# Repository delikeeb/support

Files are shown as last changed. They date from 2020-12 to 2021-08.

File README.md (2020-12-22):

# `dELIKEEb` Support Repository

This is a supporting repository for the keyboards that I made. All the keyboards here are hobby projects, and are not commercially available. 

README is under construction, but you check the folders if you need firmware for your keeb!

If you have question, PM me via `u/delikeeb`

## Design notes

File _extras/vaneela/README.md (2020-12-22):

# Flatbread60 Support Page

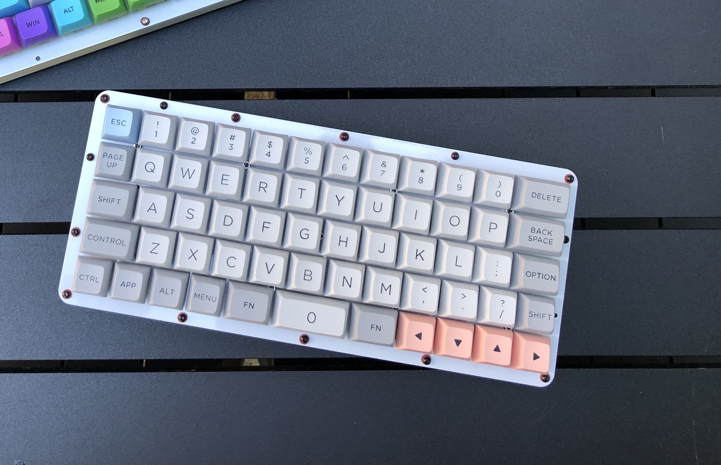
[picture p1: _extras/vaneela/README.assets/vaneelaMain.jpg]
vaneelaMain


## Pinout

MATRIX_ROW_PINS { F6, F7, B3, B2, B6 }

MATRIX_COL_PINS { F4, F5, B5, B4, E6, D7, C6, D4, D0, D1, D2, D3 }

## Firmware

I will push the firmware to the official QMK repo, so that you can use QMK configurator. Until then, you can compile the firmware using the raw file in the designated directory with a conventional QMK dev setup. Or, you can use the complied .hex file with QMK toolbox. The comilpled file has a `almost default` Preonic 48 key layout. Please check `keymap.c` file. 

## Housing Materials

- STL file for 3D printed middleware is uploaded, which is 16mm in height.

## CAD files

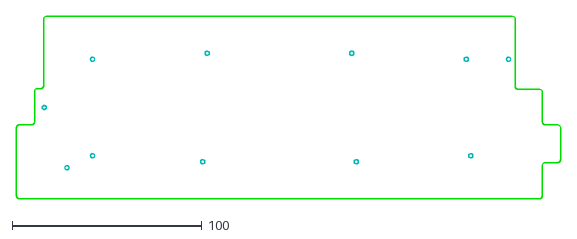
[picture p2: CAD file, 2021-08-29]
_extras/naan/prototypeCases/naan_rev1.5-plateCase_bottom.dxf
286.6 x 96.1

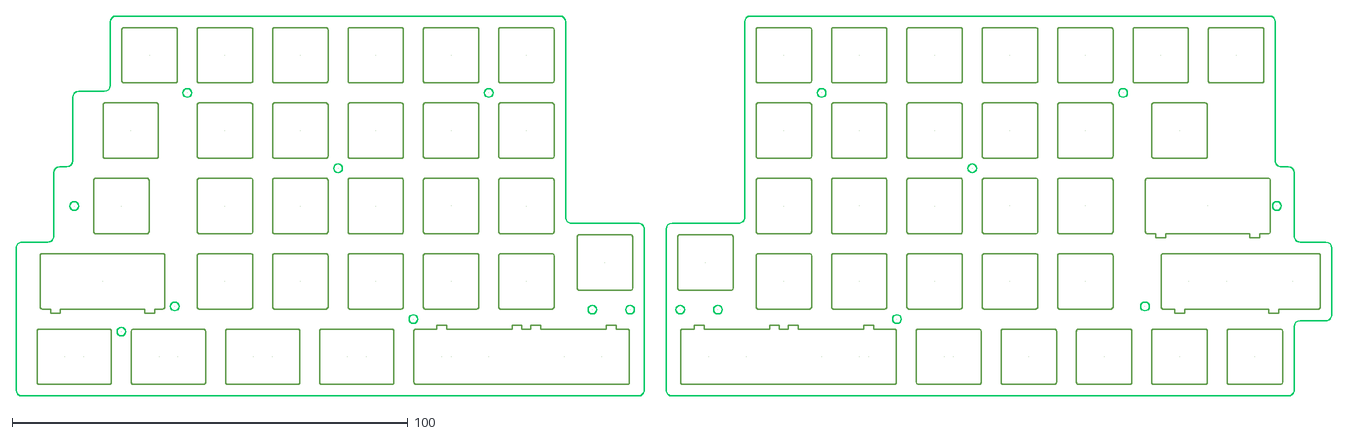
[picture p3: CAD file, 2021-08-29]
_extras/naanSplit/prototypeCases/naanSplit_rev2.x-platecase_switch.dxf
332.6 x 96.1

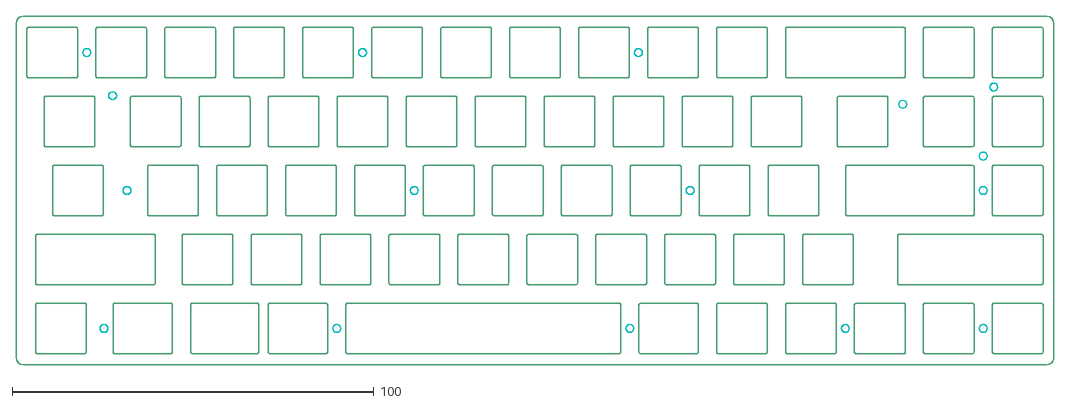
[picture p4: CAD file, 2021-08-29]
_extras/vaguetteLite/vaguetteLite_rev3.2-plateCase_switch.dxf
286.7 x 96.2

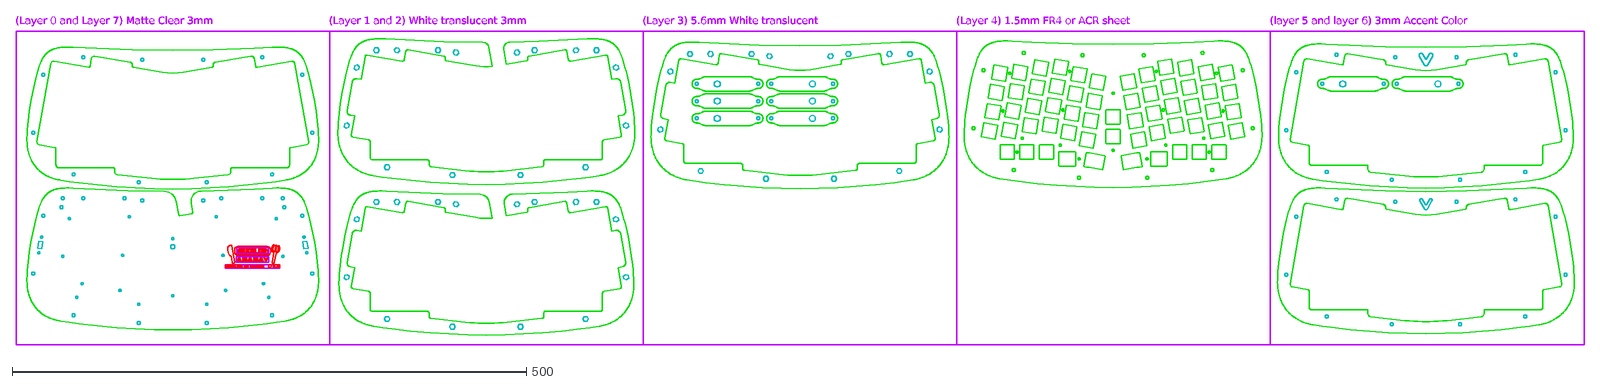
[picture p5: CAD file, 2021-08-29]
_extras/vanana/rev2.5_GB/ARC case/Vanana_rev2.5_GB_ACRcase_release.dxf
(layer 5 and layer 6) 3mm Accent Color
(Layer 3) 5.6mm White translucent
(Layer 1 and 2) White translucent 3mm
(Layer 4) 1.5mm FR4 or ACR sheet
(Layer 0 and Layer 7) Matte Clear 3mm

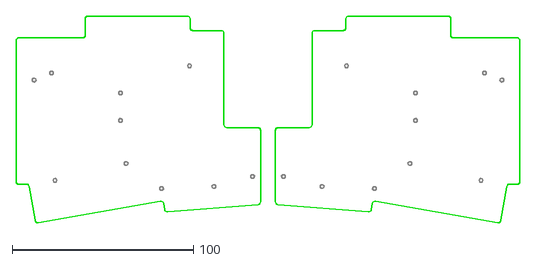
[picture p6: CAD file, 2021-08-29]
_extras/vananaSplit/prototypeCases/rev1.2/vananaSplit_rev1.2-plateCase_bottom.dxf
278.1 x 114.1

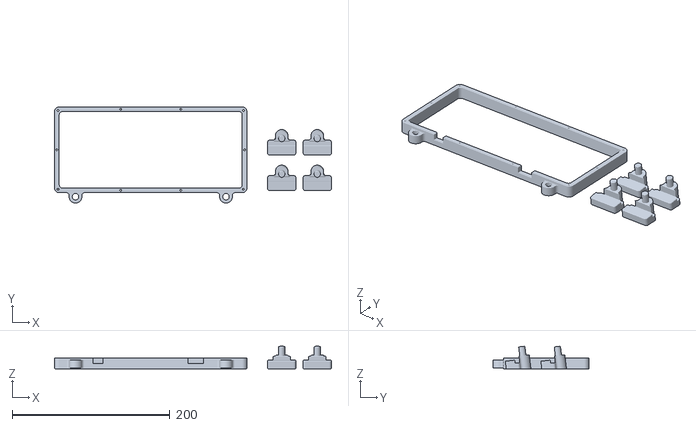
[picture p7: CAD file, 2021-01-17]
_extras/waaffle/plateCase_middleWare/middleware_60config.stl
350.7 x 121.8 x 28.7

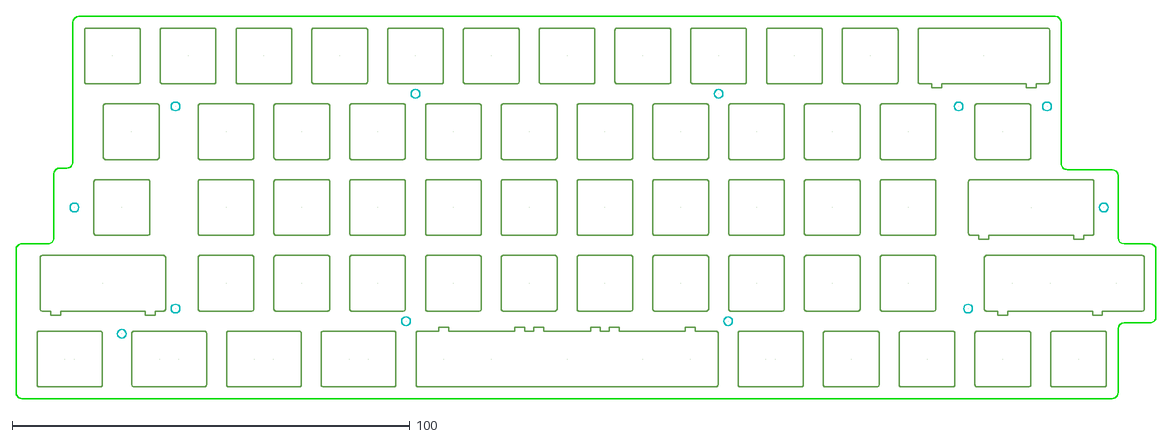
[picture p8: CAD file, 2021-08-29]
_extras/naan/prototypeCases/naan_rev1.5-plateCase_switch.dxf
286.6 x 96.1

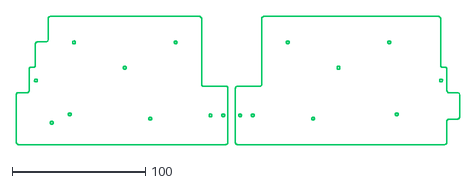
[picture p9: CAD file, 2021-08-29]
_extras/naanSplit/prototypeCases/naanSplit_rev2.x-platecase_bottom.dxf
332.6 x 96.1

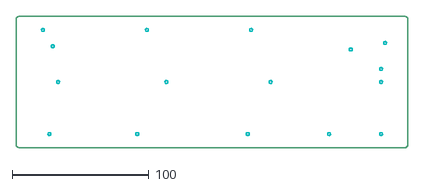
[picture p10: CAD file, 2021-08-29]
_extras/vaguetteLite/vaguetteLite_rev3.2-plateCase_bottom.dxf
286.7 x 96.2

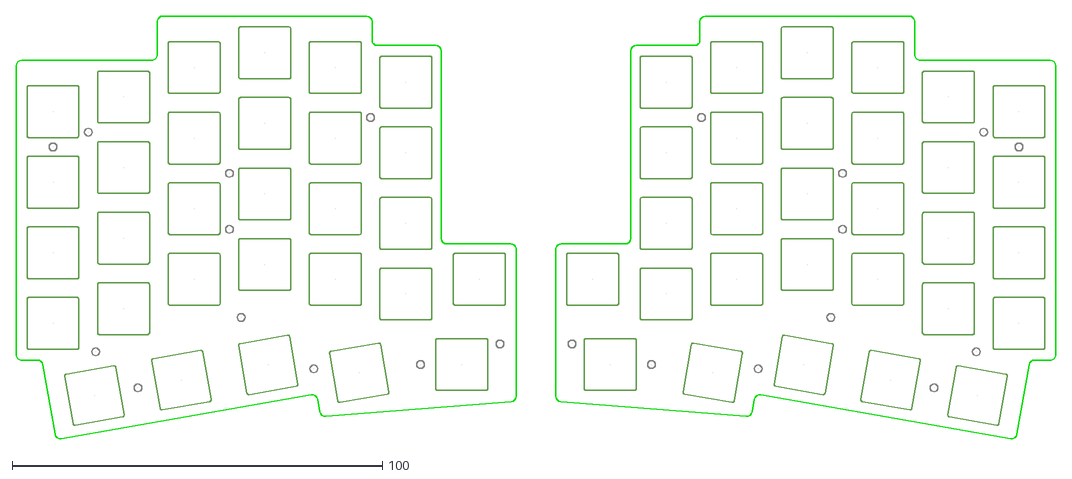
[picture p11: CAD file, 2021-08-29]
_extras/vananaSplit/prototypeCases/rev1.2/vananaSplit_rev1.2-plateCase_switch.dxf
280.6 x 114.1

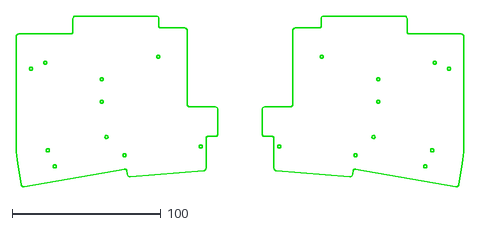
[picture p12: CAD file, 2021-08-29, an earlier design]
_extras/vananaSplit/prototypeCases/rev1.1/vananaSplit_rev1.1-plateCase_bottom.dxf
301.2 x 114.9

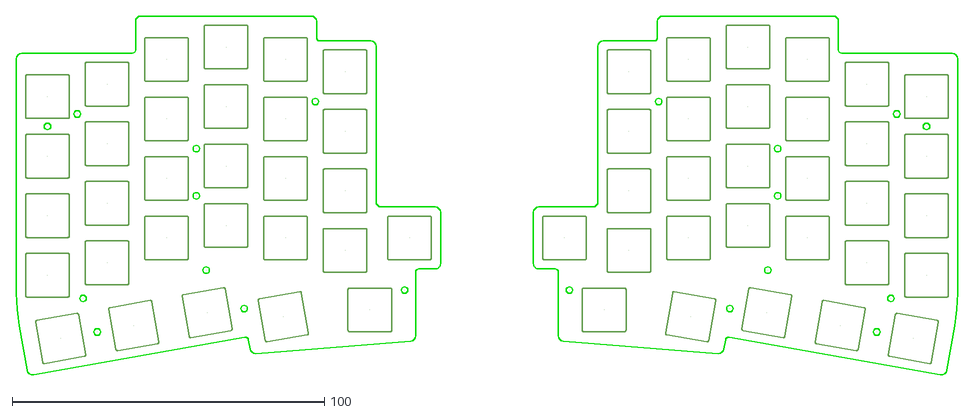
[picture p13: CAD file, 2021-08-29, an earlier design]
_extras/vananaSplit/prototypeCases/rev1.1/vananaSplit_rev1.1-plateCase_switch.dxf
301.2 x 114.9

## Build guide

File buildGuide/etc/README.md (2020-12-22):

# General guide for selecting/sourcing parts

This is a supporting repository for the keyboards that I made. All the keyboards here are a hobby project, and are not commercially available. 

## How to find and where to buy hardware?

When I sell some extra pieces, I usually do not include hardware because it's selection varies on your setup, e.g., soldered build, hot-swap build, ProMicro build and so on. Here I will write how to select parts to suit your build in my preferred way. However, do note that there is no right way to doing it. There are various ways to assemble a keyboard, so please take this as a reference. 

Most of the keyboards and cases that I make have the structure like this:

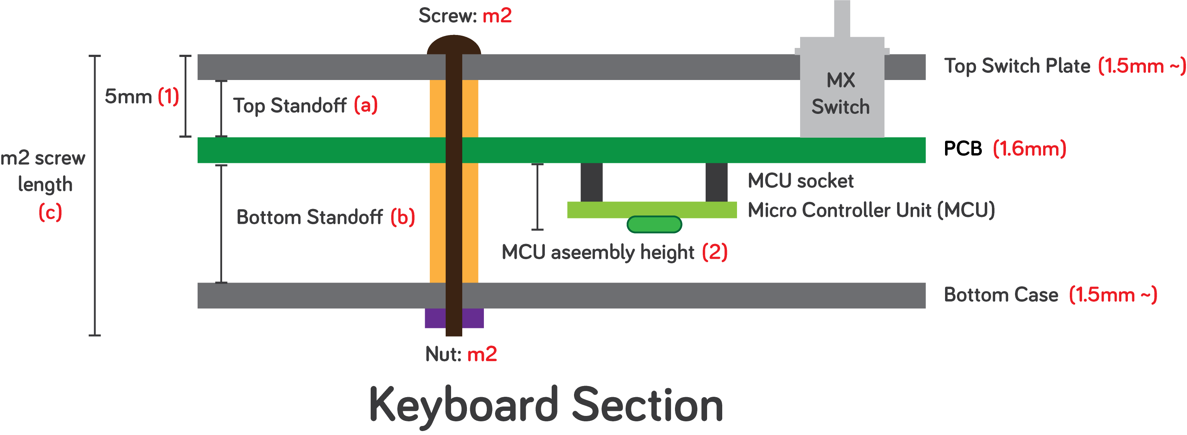
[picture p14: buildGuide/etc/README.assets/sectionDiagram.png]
sectionDiagram


As you can see here, you usually only need to decide the length of the standoffs (a), (b), and the length of a m2 screw (c). 

### Invariable factors

- Most single layered PCBs are 1.6mm in thickness. 
- Most stainless steel plates are 1.5mm in thickness.
- The distance between the top of PCB and the top of the switch plate **(1)** is 5mm when using MX switches. If you use 0305 Mil-Max hot-swap sockets, they will push the switches up about **0.5mm**, so the distance **(1)** will be about **5.5mm.**
- MCU assembly height **(2)** depends on your selection of parts. If want to go very cheap, you can use ProMicro and cheap machine pin sockets, and it will make the distance **(2)** **8mm**. If you want to go fancy, you can use ultra-low profile sockets and Elite-C, which will then make the distance **(2) 6mm.**

### Choosing a top standoff (a)

Based on the invariable  factor above,

-  If solder your switches and use a FR4 switch plate, you need a m2 standoff that fills 5mm - 1.6 mm = 3.4mm. Because a 3.4mm standoff does not exist, you can just use **3mm m2 standoff** and **0.5mm m2 washer**. 
- If you go for a hot-swap build with a 7304 Mil-Max socket, you you need a m2 standoff that fills 5.5mm - 1.6 mm = 3.9mm, and you can just use **4mm m2 standoff** . 

### Choosing a top standoff (b)

Based on the invariable  factor above,

- If you go with the cheap option, the minimum height of the bottom standoff (b) is **8mm.** 
- If you go with the fancy option, the minimum height of the bottom standoff (b) is **6mm.** 
- Choosing the minimum height may let your MCU touch the bottom case. 

### Choosing a screw (c)

Now you just need to add them up. To tighten things up with m2 nuts, you need about 2mm of a margin at the tip of s screw. So the length of the screw of your choice will be:

**Minimum screw length** = top switch plate thickness + top standoff height + PCB height (~1.6mm) + bottom standoff height + bottom case thickness + 2mm margin.

### Middleware height

If you want to add a middleware to prevent flexing in a FR4 case setup, the height of the middleware will be just the sum of the top and bottom standoff heights and the PCB thickness (1.6mm).

### Examples

- If you want to go with a cheapest setup with a FR4 plate case, Promicro, and soldered build: 
  - You can use 3mm standoffs and 0.5mm washers for the upper chamber.
  - You can use 8mm standoff for the lowerchamber.
  - You can use 3 + 1.6 + 8= 13.6 mm middleware. To make things simple, you can add 0.5mm washers to the bottom standoffs, and just make 14mm middleware.
  - The total thick of the case will be 1.6mm + 14mm (middleware) + 1.6mm = 17.2mm. So, You can use 20mm m2 screws.
- If you want to go with a fancy setup with a 0305 MilMax socket, SS plate, custom 3D printed case, Elite-C and ultra low profile sockets, and if we assume that the bottom plate of the 3D printed case is 3mm:
  - You can use 4mm standoffs for the upper chamber.
  - You can use 6mm standoffs for the upper chamber.
  - You can use   = 11.6 mm middleware. To make things simple, you can add 0.5mm washers to the bottom standoffs, and just make 12mm middleware.
  - The total thick of the case will be 1.5 mm (SS plate) + 12mm (middleware) + 3mm (3d printed case) = 16.5mm. So, you can use screws longer than 18.5 mm. 18mm will be also ok. 

## Where to buy?

Below are the places that I check for parts. 

https://docs.google.com/spreadsheets/d/1yFxFad6Fp7bDsbbrUbymgozWEZLEjbd6_0tXTSnRA-c/edit?usp=sharing

- For cheap items like screws and standoff:
  - Amazon: expensive, but takes a few days to be delivered. 
  - Walmart: somewhat expensive, and takes about two weeks to be delivered.
  - Aliexpress: dirt cheap, but takes forever to be delivered. 

If you are ok with a slow progression, I recommend to buy a bunch from Aliexpress. 

- For fancier items like ultra low profile sockets:
  - Digikey
  - Mouser

Do not buy cheap items like standoffs or screws from Digikey or Mouser. They are pretty expensive. I usually buy a lot of 18mm, 20mm screws and 4mm, 6mm, 8mm standoffs, and 0.5mm fiber washers.

### Note

- You can be flexible in sourcing parts. For example, If you need 8mm standoffs but could only find 7mm standoffs available, you can just buy 7mm ones and add two 0.5mm fiber washers. 

##  Where to make a custom case and plate?

- https://sendcutsend.com/
- https://www.treatstock.com/

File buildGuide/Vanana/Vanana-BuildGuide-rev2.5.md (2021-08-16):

# Vanana (rev 2.5 GB) Build Guide

Last Update: 210620

We will go through the process of fully assembling Vanana.

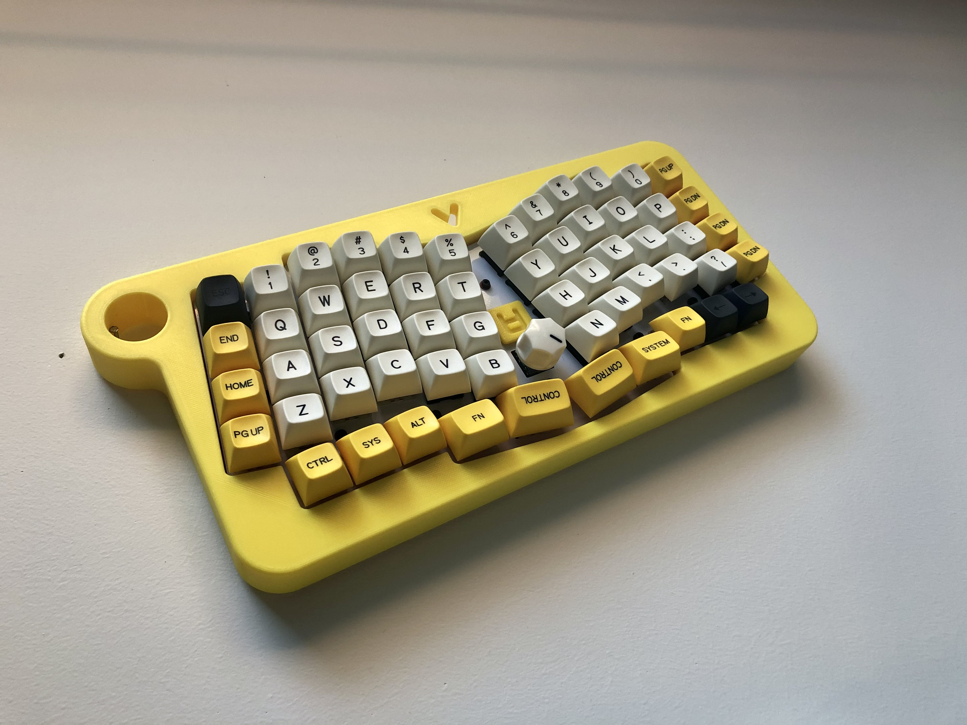
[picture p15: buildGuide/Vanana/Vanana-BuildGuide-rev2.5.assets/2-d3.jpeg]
2-d3


## Required Hardware:

**Overview** 

01-Overview@2x

**Hardware used to make this build:** 

- Vanana Thicc Case x 1 
- Vanana Plate x 1 
- m2 screws 7mm x 4
- m2 screws 18mm x 12
- m2 Standoff 5mm x 12 
- m2 Standoff 4mm x 12
- m2 Nuts x 12
- m2 Washer x 12 
- EC11 Rotary Encoder x 1 (optional)
- Dupont cable x 3 (optional for the encoder 2 or RGB) 
- Right angle headers x 9 (optional)
- Straight angle headers (This usually comes with your MCU. Make sure that the height of the insulation is less than or equal to 3mm)

**Optional hardware for a wireless build:** 

- Dupont cable x 6 (2 cables for RGB, Power switches, and battery) 
- Slide Switch x 2
- LiPo Battery **(will not be included in the GB kit)**

**Optional hardware for a Hot-swap functionality:** 

- Ultra-low profile Pin Socket (for a MCU board) 
- Round machine pin x 12 (for a MCU board) 
- Mil Max 0305 x 120 (for key switches) 

**And, of course:**

- MCU board of your choice (Pro Micro, Elite-C, Nice!nano)
- Switches and keycaps.

**Useful quality-of-life tools (links are only for reference):**

- Masking tape like [this one](https://www.amazon.com/AmazonBasics-Masking-Tape-Inch-Rolls/dp/B07QHSKGMH)
- M2 hex nut driver like [this one](https://www.amazon.com/uxcell-Non-Magnetic-Point-Driver-3-Inch/dp/B07DXZJQ4S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)
- M2 hex driver like [this one](https://www.amazon.com/gp/product/B001ATKWJY/ref=ppx_yo_dt_b_search_asin_title?ie=UTF8&psc=1) 
- or, the all-in-one driver set [this one](https://www.amazon.com/iFixit-IF145-299-4-Driver-Bit-64pc/dp/B0189YWOIO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)

## Assembly Order

1. Soldering on PCB: MCU Board sockets and right-angle headers
2. Switchplate Assembly
3. (if your build is soldered) Keyboard Switches
4. (if your build is hot-swappable) Hot-swap sockets
5. Assembling MCU board onto the PCB
6. (if your build is wireless) Battery and external Switches

## Assembly instruction

### Step 1. Soldering on PCB: MCU Board sockets and right-angle headers

On the Group buy version, all the essential parts are pre-soldered, which includes:

- Diodes
- Capacitors
- 2x onboard slide switches
- Reset switch
- RGB Underglow LEDs

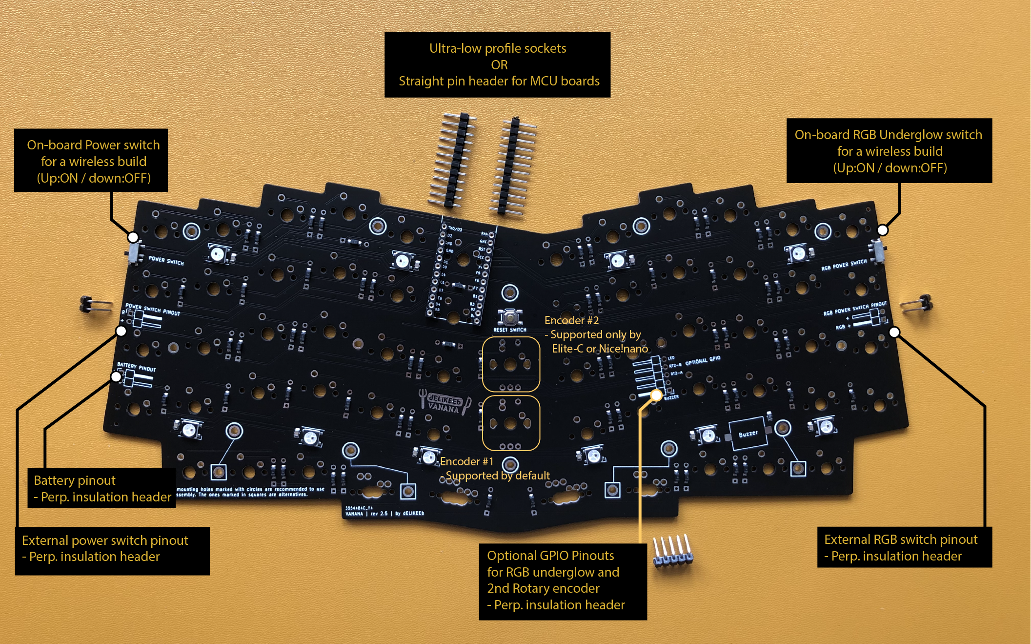
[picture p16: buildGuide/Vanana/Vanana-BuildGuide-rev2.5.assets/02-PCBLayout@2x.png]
02-PCB Layout@2x
You only need to solder a few parts on PCB and assemble an MCU board on it. 

**Parts you need:**

- Ultra-low MCU board sockets **or** straight pin headers. 
- (wireless setup only) 3 x 2-pos Right angle headers.
- (Optional for RGB underglow and the encoder 2) 1 x 3-pos (or 5) Right angle header.
- **Note*: with GB version PCBs, you can use a right-angle header with a parallel insulation for external switches and battery connections. Extra GPIOs will still need the one with a perpendicular insulation.**  

**Steps**:

1. Insert ultra-low profile sockets (for a hot-swap build) **or** straight pin headers (for a soldered build) from the back of the PCB. The photo below shows compatible sockets and headers. You will use **one of them** depending on your build. Make sure the height of the insulations of the header or sockets (black plastic part in the photo below) are less than or equal to 3mm. Most straight pin headers that come with MCU boards have insulations whose height is less than 3mm. Masking tape will help you secure the parts when soldering them. Solder MCU sockets or headers from the front of the PCB.
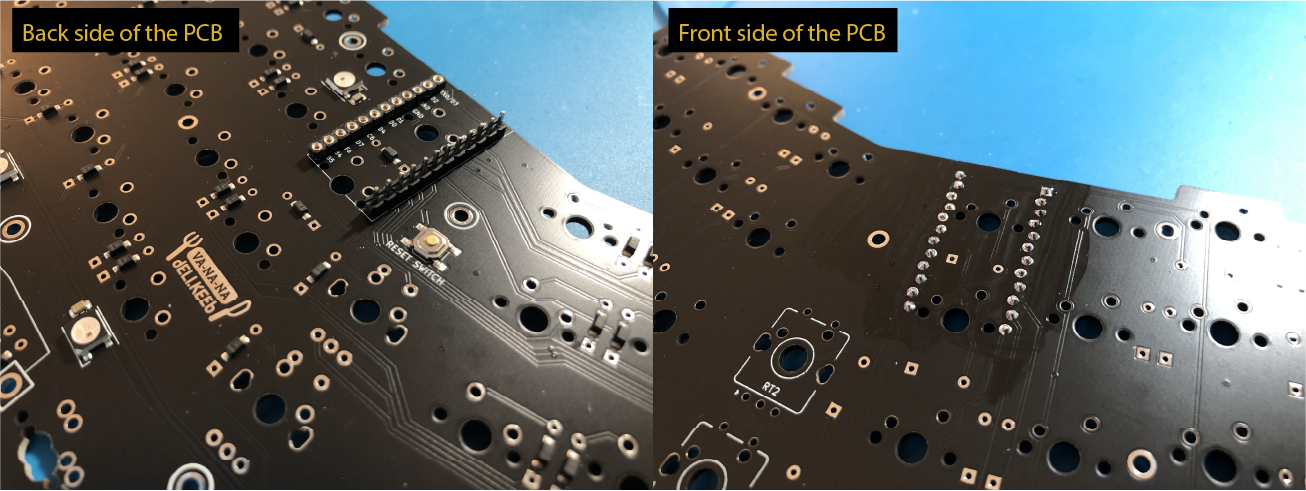
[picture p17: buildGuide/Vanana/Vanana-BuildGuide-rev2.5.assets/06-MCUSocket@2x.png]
06-MCU socket@2x
   
2. Note that there are two onboard switches on both sides of the PCB. One is for RGB, and the other is for the Power switch. (Down: OFF/ Up: ON). If you are building a **wired Vanana, just toggle up the switches and skip to the next section (Step 2. Switch Plate Assembly). If you are building a wireless Vanana with a plate case kit**, you can also skip to the next section.
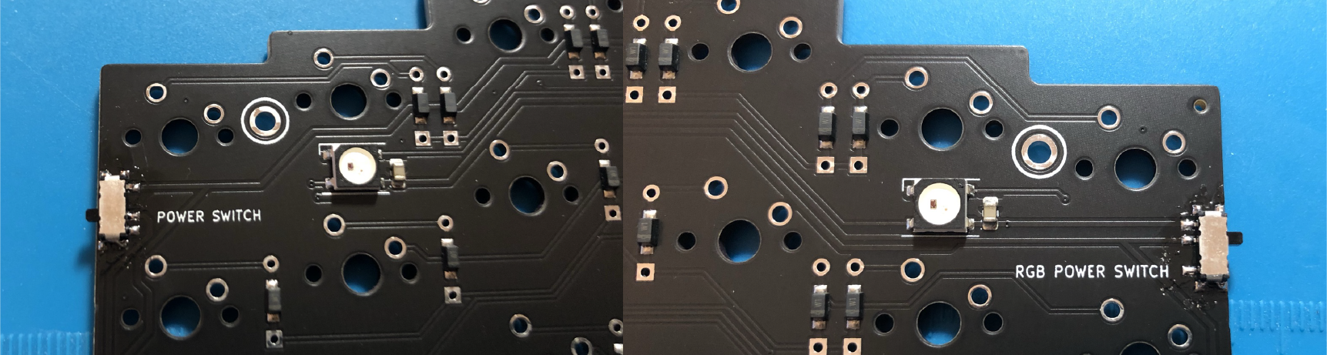
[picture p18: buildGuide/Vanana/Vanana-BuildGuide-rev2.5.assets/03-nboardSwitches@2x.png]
03-nboardSwitches@2x
   
3. If you are building a **wireless Vanana with 3D printed cases**, it is time to solder 3 x 2-pos right-angle pin headers to use external switches and batteries. 
   - At the time of designing the board, the RGB switch was added to cut off the quiescent current draw of RGB LEDs. Now the software RGB control of ZMK is equivalent to the hardware switch, so you can skip soldering the RGB switch header pin if you do not mind using a software switch to control RGB underglow.
   - Note that there are two types of right-angle headers included. Use the one with an insulation perpendicular to the PCB for this step. The other one will be used to mod an MCU board.
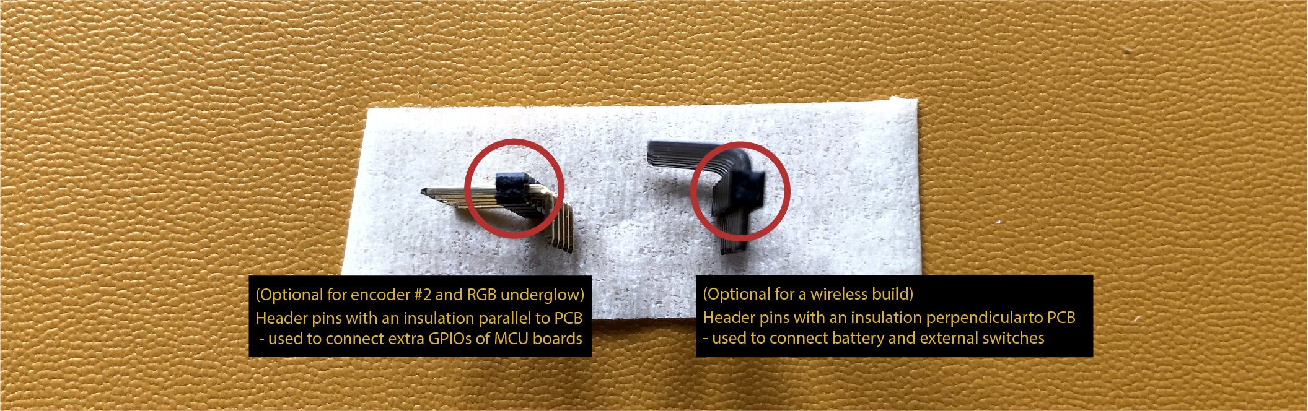
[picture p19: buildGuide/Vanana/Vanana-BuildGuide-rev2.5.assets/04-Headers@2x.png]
04-Headers@2x
     

- Prepare the headers as shown in the photo. Place the right-angle pin headers on the back of the PCB. You may want to use tape to secure the header. Solder the pin headers from the front of the PCB. Place the header pins flat on the PCB. 
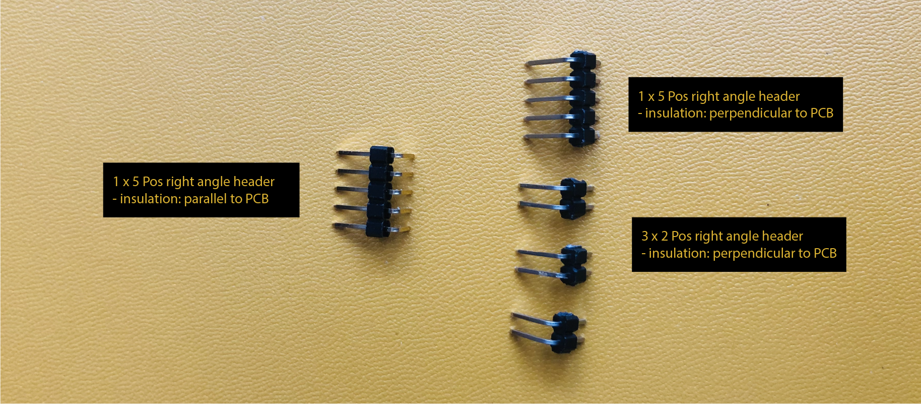
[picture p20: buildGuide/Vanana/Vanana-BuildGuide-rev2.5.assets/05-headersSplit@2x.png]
05-headers split@2x
  
- Solder the right angle headers onto the PCB as shown in the photo. Masking tape will help you secure the parts. There are three places to install the 2-pos headers. Place the headers on the back of the PCB, and solder them from the front. 
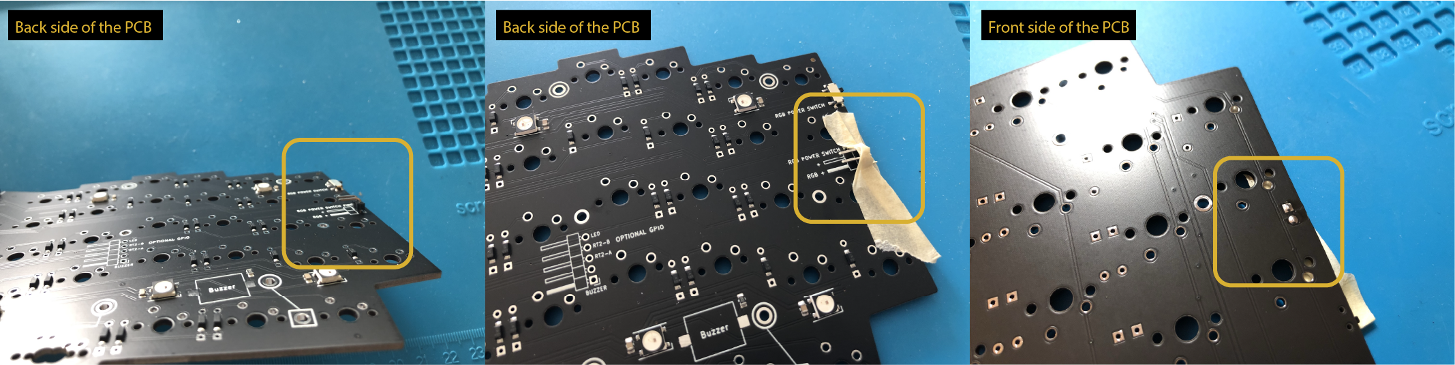
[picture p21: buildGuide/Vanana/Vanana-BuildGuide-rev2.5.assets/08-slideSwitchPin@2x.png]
08-slideSwitchPin@2x
  

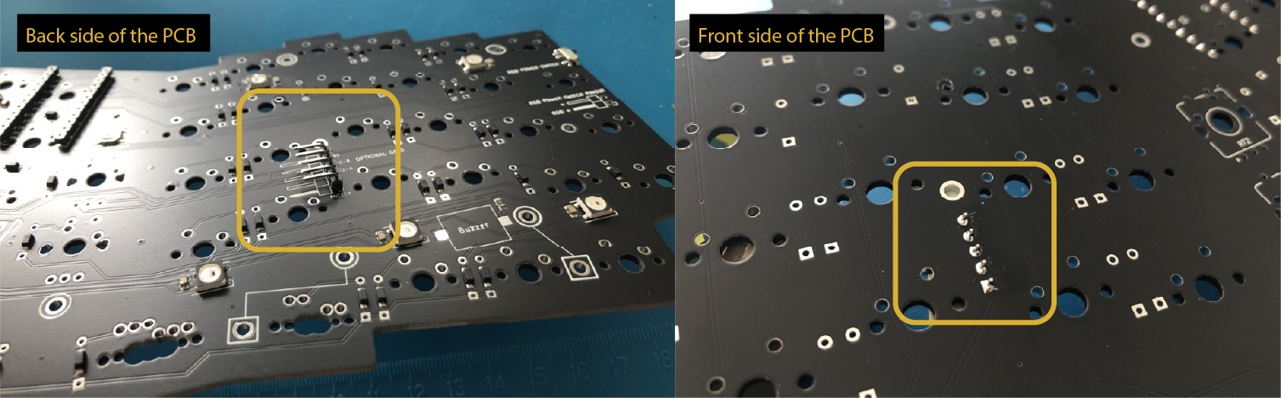
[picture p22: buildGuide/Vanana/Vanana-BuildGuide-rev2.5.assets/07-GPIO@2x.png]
07-GPIO@2x
4. If you want to enable RGB underglow or the encoder at position 2, solder the header on the PCB as below. The procedure is the same as the step above. 
5. If you are going to use rotary encoders, solder it on the PCB.
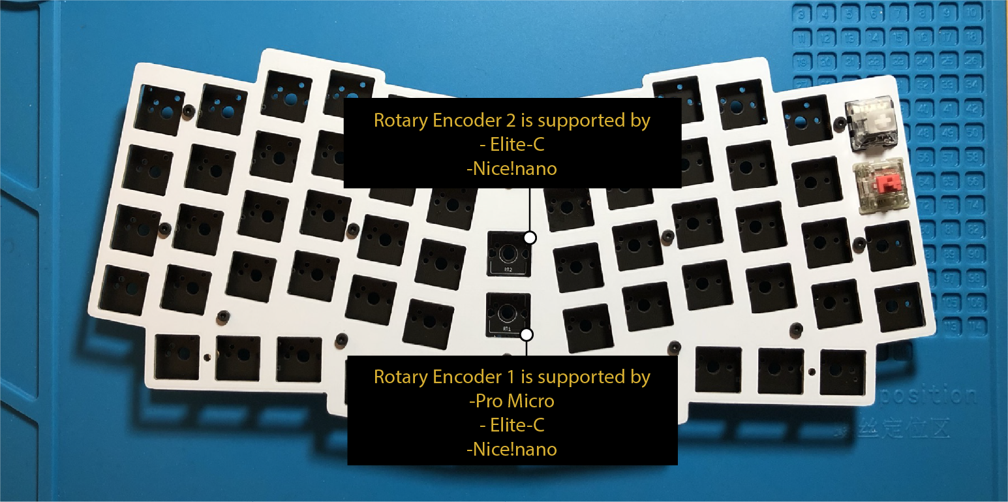
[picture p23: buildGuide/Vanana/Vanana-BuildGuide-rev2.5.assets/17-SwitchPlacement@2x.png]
17-Switch placement@2x
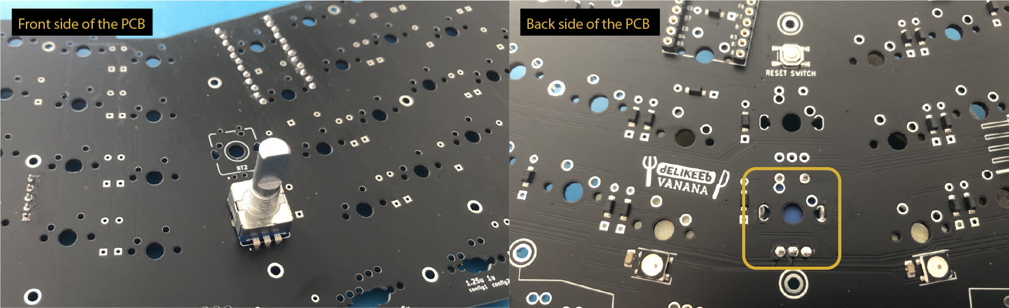
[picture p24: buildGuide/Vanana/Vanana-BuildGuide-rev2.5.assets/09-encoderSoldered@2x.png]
09-encoder soldered@2x
   - A rotary encoder at position 1 is supported by all Pro Micro compatibles and Nice!nano by default. However, only Nice!nano and Elite-C supports a rotary encoder at position 2 because it uses extra GPIO pins on Elite-C and Nano, which will be covered in the later section. Likewise, RGB underglow is supported only with Elite-C and Nice!Nano.

### Step 2. Switch Plate Assembly

**Parts you need:**

- 12 x m2 screws 
- 12 x Short m2 standoffs

**Steps**:

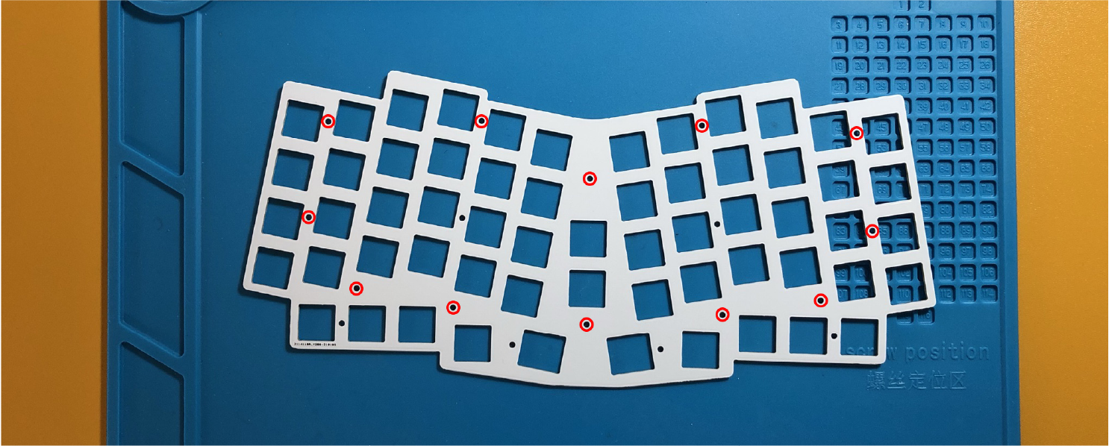
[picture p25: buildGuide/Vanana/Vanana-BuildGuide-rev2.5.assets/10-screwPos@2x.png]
10-screwPos@2x
1. You are free to change the positions of screws at your preference. The ones marked red in the photo above are the recommended locations.
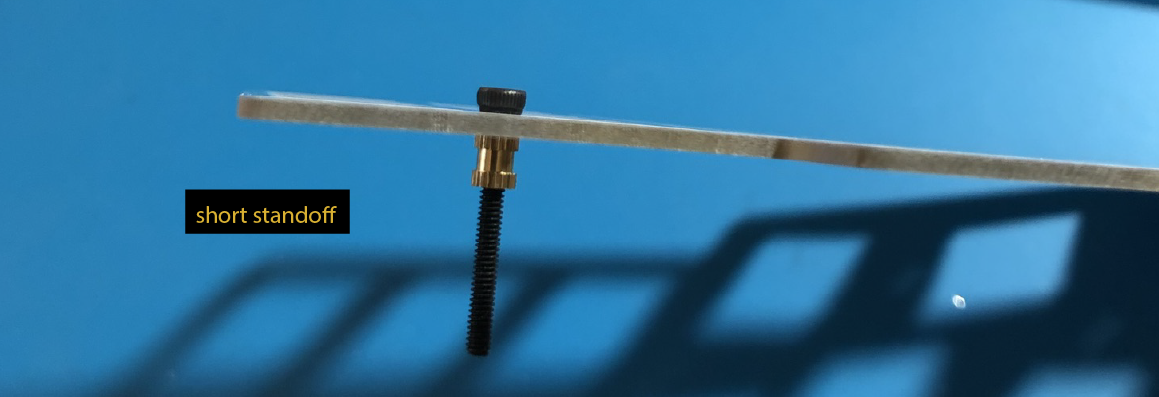
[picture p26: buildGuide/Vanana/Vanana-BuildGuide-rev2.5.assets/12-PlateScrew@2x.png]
12-PlateScrew@2x
2. Insert screws into the switch plate from the top.
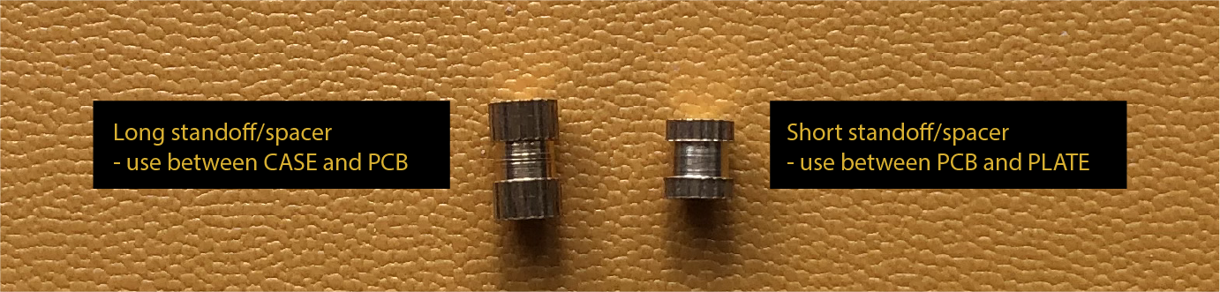
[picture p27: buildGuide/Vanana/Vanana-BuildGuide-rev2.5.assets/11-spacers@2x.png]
11-Artboard 25@2x
3. Insert **short M2 standoffs/spacers** (4mm one in GB version kits) and tighten them. You can do this by hand. However, if you want a rock-solid build, use a small plier to hold the standoffs/spacers and an m2 hex screwdriver to tighten them). 
4. Assemble the PCB and the switch plate. Place **the long standoffs** and tighten them.  
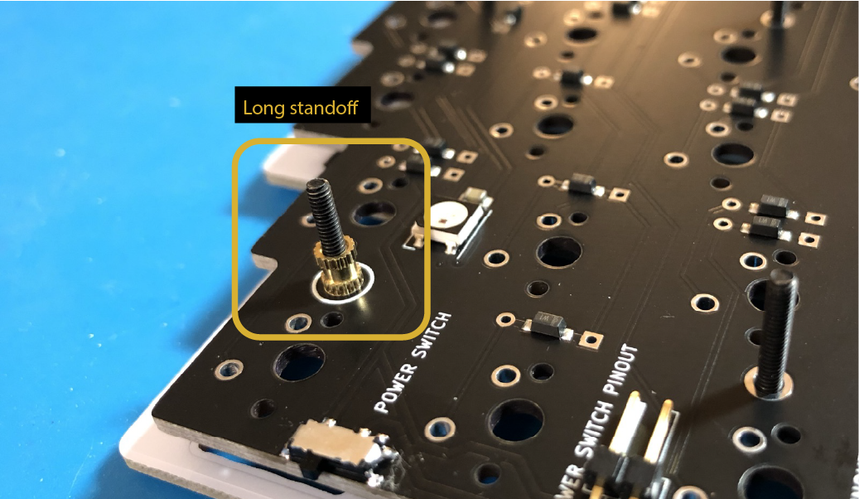
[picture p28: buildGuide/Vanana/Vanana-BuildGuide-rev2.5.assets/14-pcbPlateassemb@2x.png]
14-pcbPlateassemb@2x
   
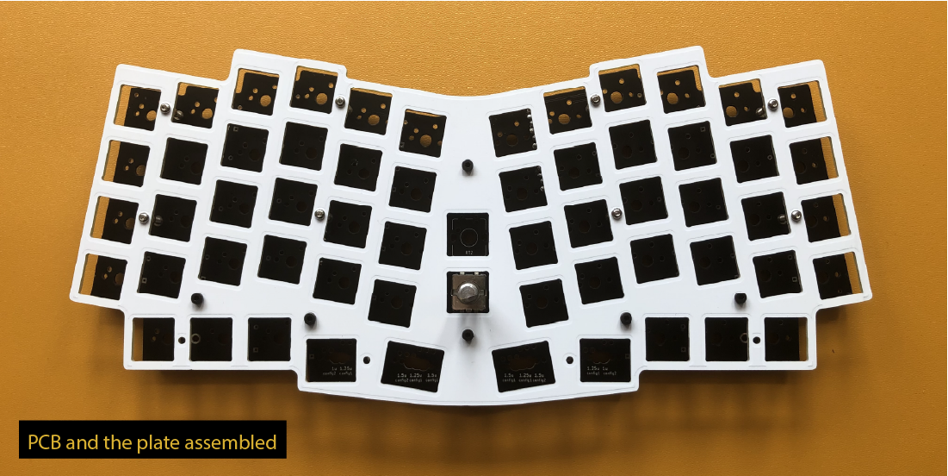
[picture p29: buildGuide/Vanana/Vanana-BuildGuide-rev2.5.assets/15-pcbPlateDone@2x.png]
15-pcb plate done@2x
   

### Step 3. (if your build is soldered) Keyboard Switches

**Parts you need:**

- 60 x keyboard switches

**Steps:**

1. Vanana GB version supports three layouts. Choose your layout and insert switches into the appropriate positions.
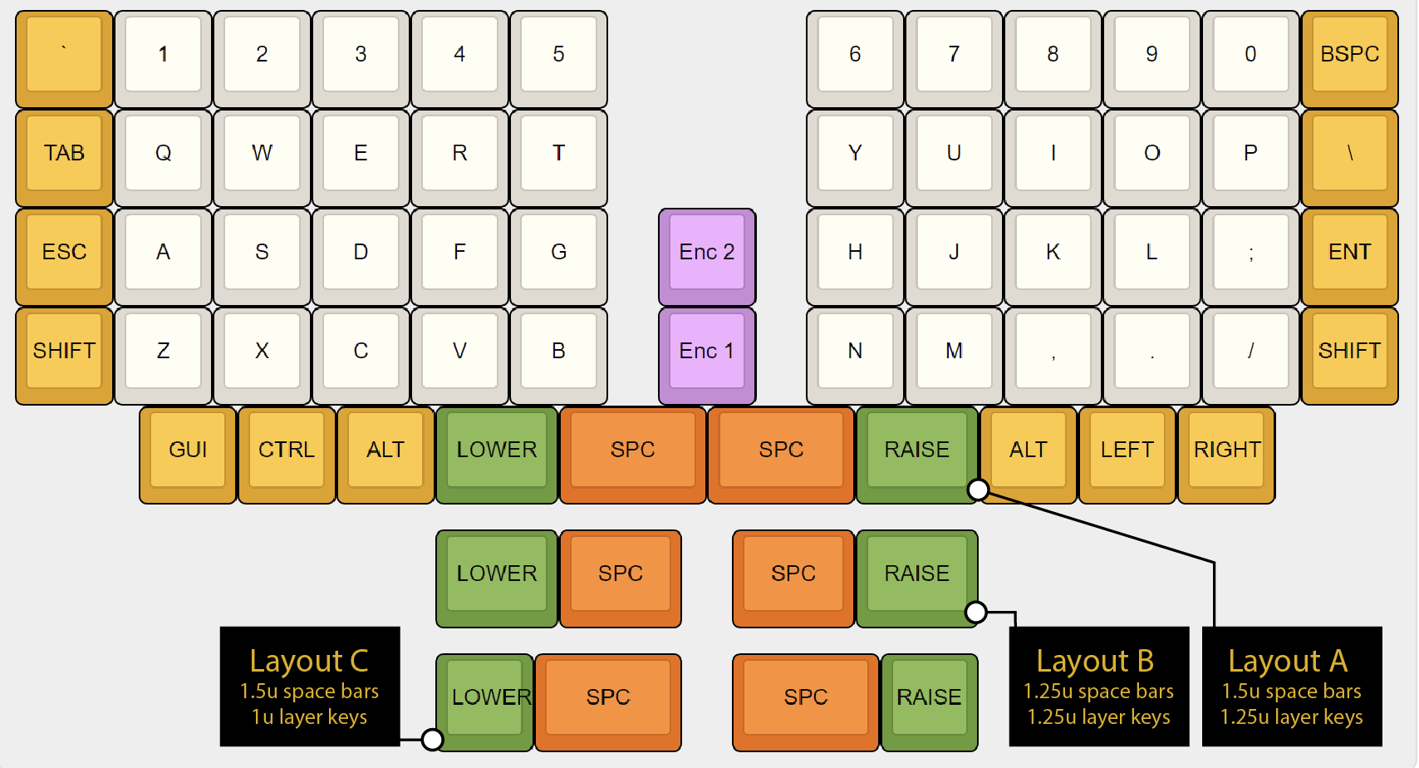
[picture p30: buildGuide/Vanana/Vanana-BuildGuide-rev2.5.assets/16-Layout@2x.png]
16-Layout@2x
   
2. Plate switches on the plate. Make sure that all the switches are fully inserted into the holes on the plate. 
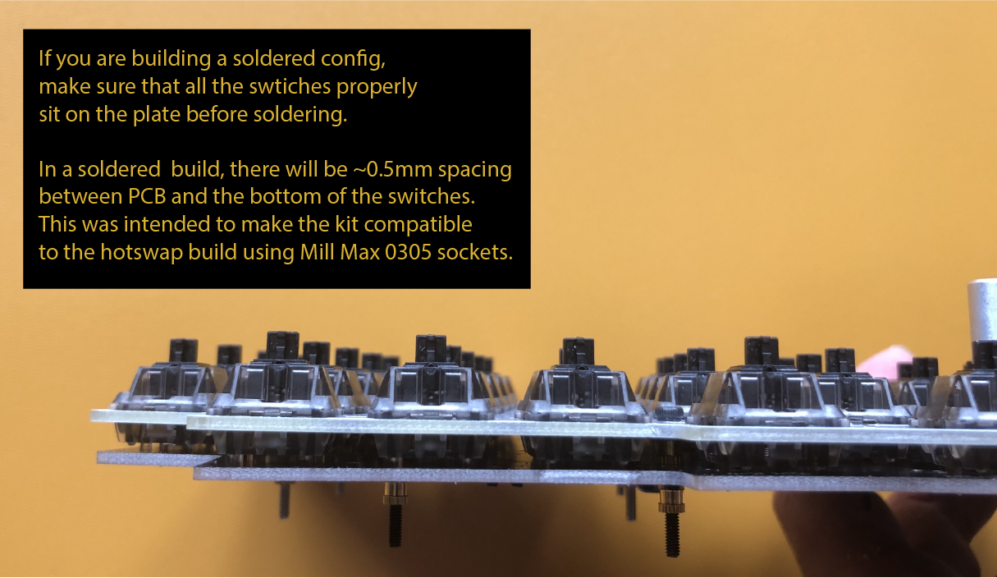
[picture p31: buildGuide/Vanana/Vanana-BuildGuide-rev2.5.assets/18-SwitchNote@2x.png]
18-Switch note@2x
   
3. Solder the key switches from the back of the PCB. 
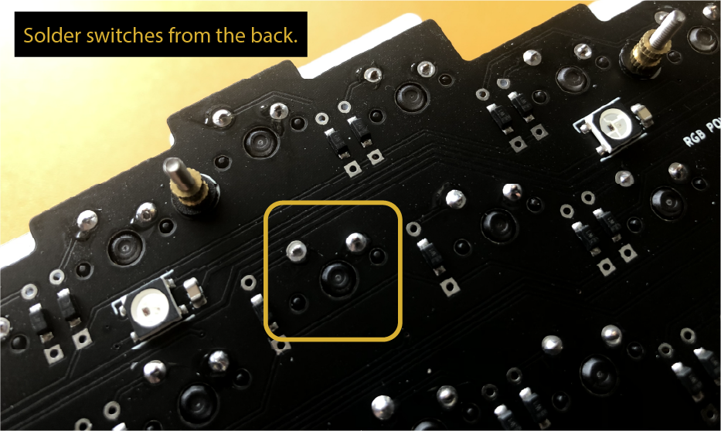
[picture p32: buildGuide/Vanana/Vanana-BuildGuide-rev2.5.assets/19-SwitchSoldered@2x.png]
19-Switch soldered@2x
   
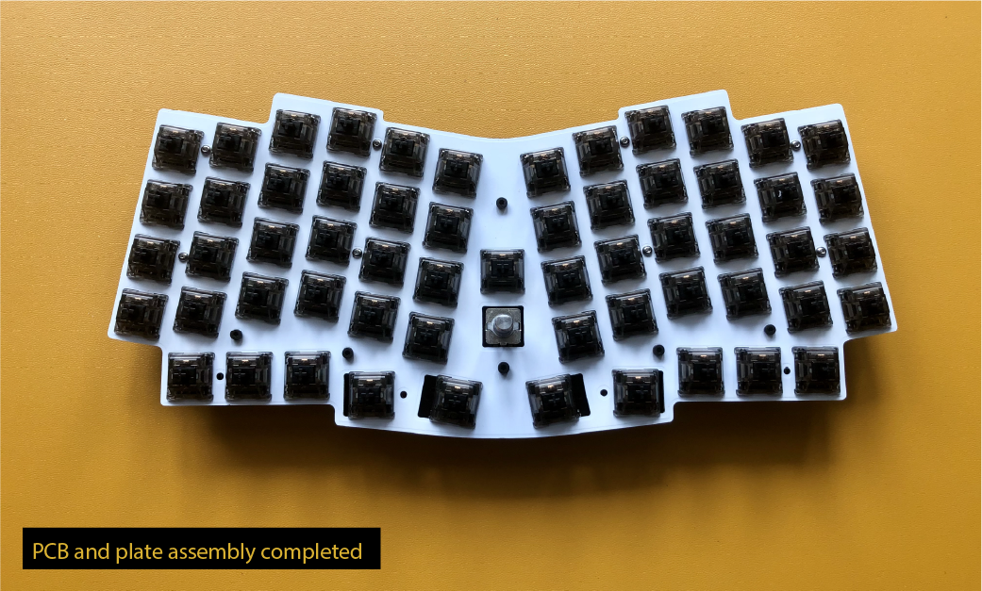
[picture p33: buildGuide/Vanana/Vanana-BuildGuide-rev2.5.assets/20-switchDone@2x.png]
20-switch done@2x
   

### Step 4. (if your build is hot-swappable) Hot-swap sockets

**Parts you need:**

- 120 x 0305(or 7305) Mill-Max hotswap sockets 

**Steps:**

1. If your build is hot-swappable, you will use 0305 or 7305 hot-swap sockets. Place hot-swap sockets into the switch holes on the PCB. A precision tweezer will be your timesaver. 
   - My favorite way of installing 0305 sockets is to solder them on one or two columns at a time. Plate them on the PCB and secure them with masking tape. Then, solder sockets from the back of the PCB. Repeat until you get all the sockets soldered.
   - If this is the first time, I highly recommend practicing with at least a few sockets on a scrap board. It is not hard, but you need to progress slowly with patience. Check video [tutorials](https://www.youtube.com/watch?v=wmkTVsZ97Vk).
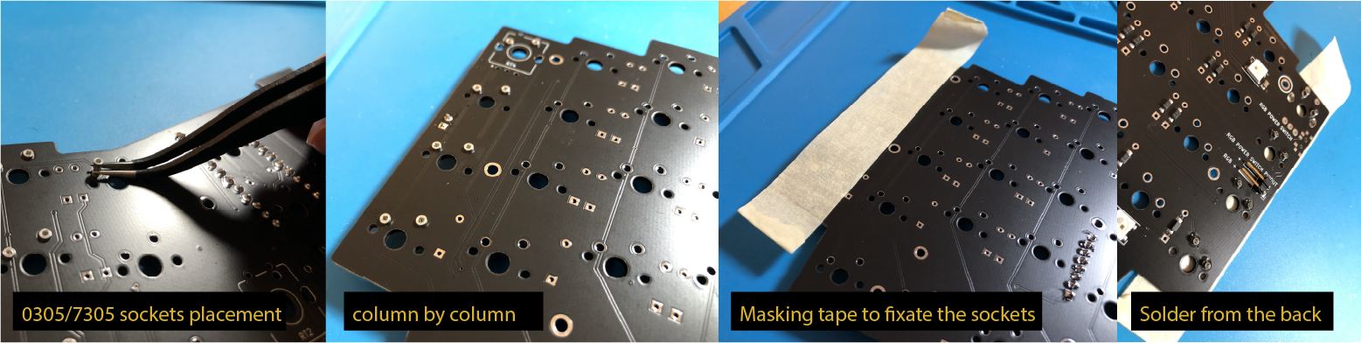
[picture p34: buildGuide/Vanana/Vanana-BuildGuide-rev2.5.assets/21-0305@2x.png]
21-0305@2x
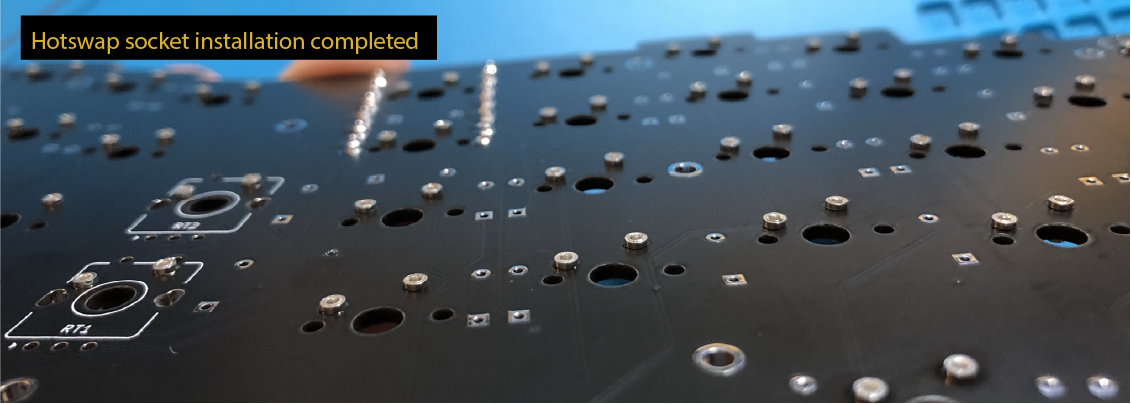
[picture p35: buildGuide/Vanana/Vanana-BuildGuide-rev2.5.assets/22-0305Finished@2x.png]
22-0305 finished@2x
   - Do not put an excessive amount of soldering iron. Use the amount of solder iron that is just enough to fill the gaps between the socket and the hole. Less is better than more in doing this. 

### Step 4. MCU board Assembly (and mod).

**Parts you need:**

- MCU board: Pro Micro compatibles or Nice!nano
- Triplet of **Short** Dupont cable

**Steps:**

1. (**optional**) If you use Elite-C or Nice!nano, and want to enable RGB underglow or the rotary encoder at position 2, the following mod will be useful. We use Dupont cable for easier maintenance
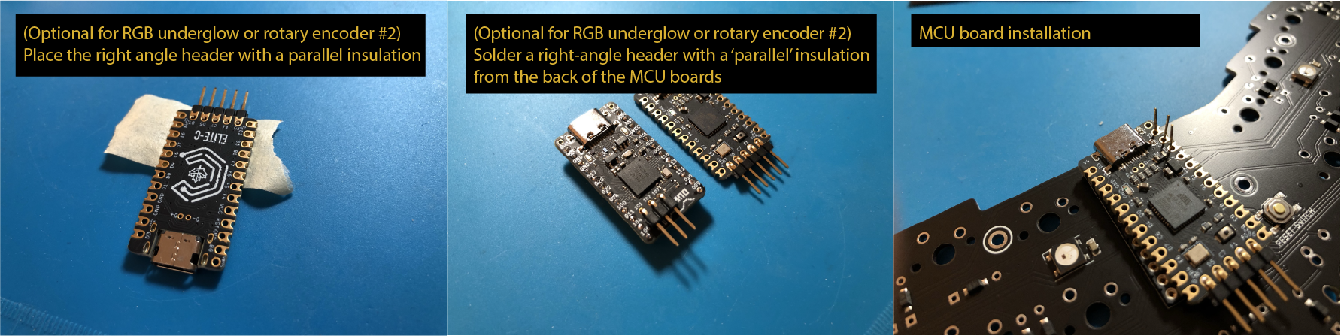
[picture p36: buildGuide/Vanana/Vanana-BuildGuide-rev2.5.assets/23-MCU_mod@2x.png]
23-MCU mod@2x
   - My preferred way of doing this is to place a right-angle header, cut the excessive header pins, secure the header pins with masking tape, and solder them on the board. 

2. If you used regular straight pin headers, place the MCU board on it and solder them. If you used ultra-low profile hot-swap sockets, place the MCU board on it, insert compatible machine pins, and solder them.

3. (**optional**) Connect the extra GPIO pins of the MCU board to PCB using the **short** Dupont cables included, if you want to enable RGB underglow or to use the encoder at position 2. 

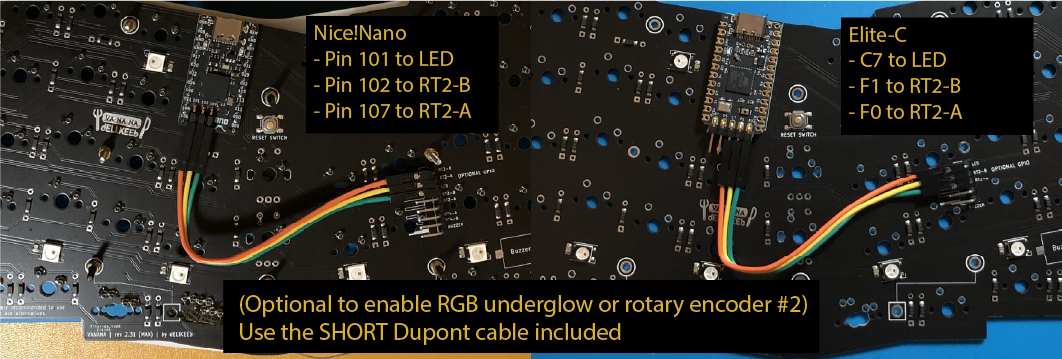
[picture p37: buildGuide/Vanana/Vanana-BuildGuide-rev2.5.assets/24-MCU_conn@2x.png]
24-MCU conn@2x
   

### Step5. (Wireless build only) External switch and battery assembly

If you are building a wired Vanana, you can skip this section. 

**Parts you need:**

- 3 x pair of **long** Dupont cable
- 4 x **short** m2 screws
- 4 x m2 nuts

**Steps:**

1. Prepare slide switches as shown below using **long** Dupont cables. 
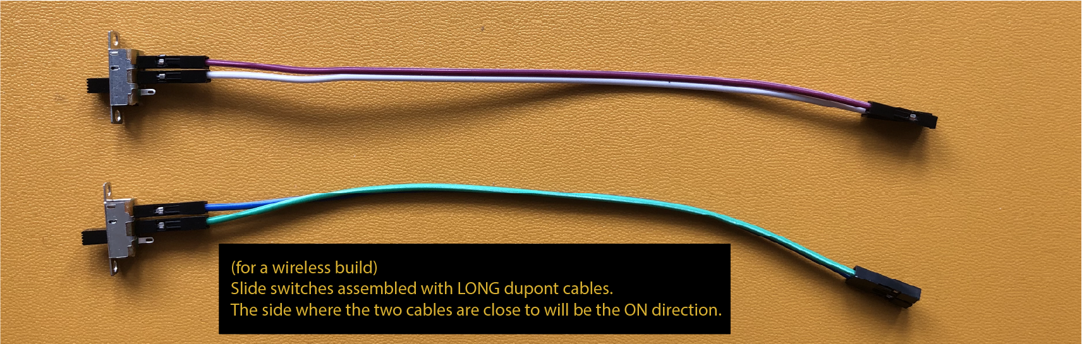
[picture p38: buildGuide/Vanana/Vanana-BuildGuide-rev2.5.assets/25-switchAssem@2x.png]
25-switch assem@2x
   

2. Place the external switches and assemble them with short m2 screws and nuts. 

   - My preferred way to do this step is to hold the nuts with a precision tweezer and tighten the screws using an m2 hex screwdriver from the other side. Connect the switches to the PCB using the long Dupont cables.
   - Note that the on/off directions of the switches depend on the cable arrangement in this step.

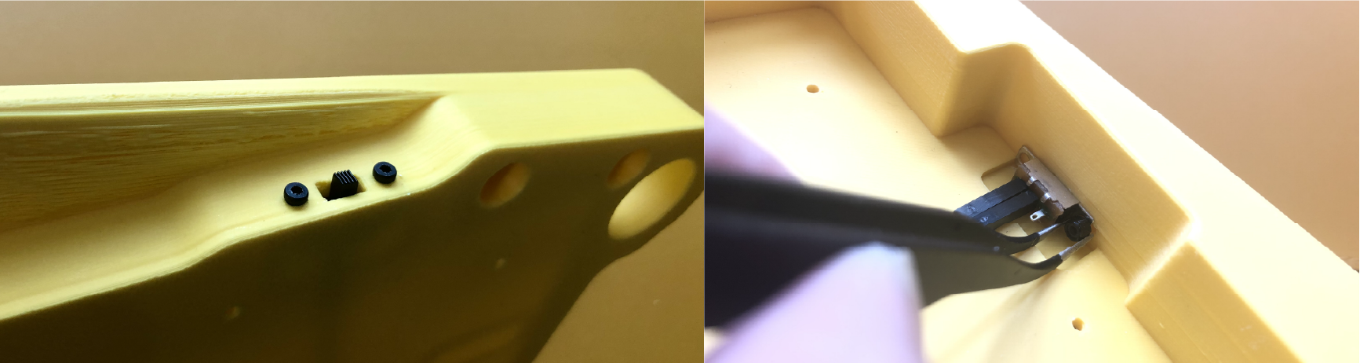
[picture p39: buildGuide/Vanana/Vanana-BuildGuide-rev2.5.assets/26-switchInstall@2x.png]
26-switch install@2x
   

3. Prepare the battery of your choice. 

   - The Vanana cases have a recessed area to place a battery. The maximum size of a battery for the GB version is 45mm(W) x 55mm(D) x 5mm(H). For a hot-swap build, batteries thinner than 4mm are recommended. If your battery has a JST cable installed, you can just connect them to the pin headers. If not, you can solder the long Dupont cables to the batteries and do the same. 

4. Connect the battery to the PCB using the long Dupont cable. 

   - **IMPORTANT**!!: The battery pinout on the board has polarity. **MAKE SURE TO CONNECT THE WIRES OF A BATTERY TO THE RIGHT SPOT**. In most cases, the red wire of a battery is +, and the black is -. However, double-check the polarity of your battery.
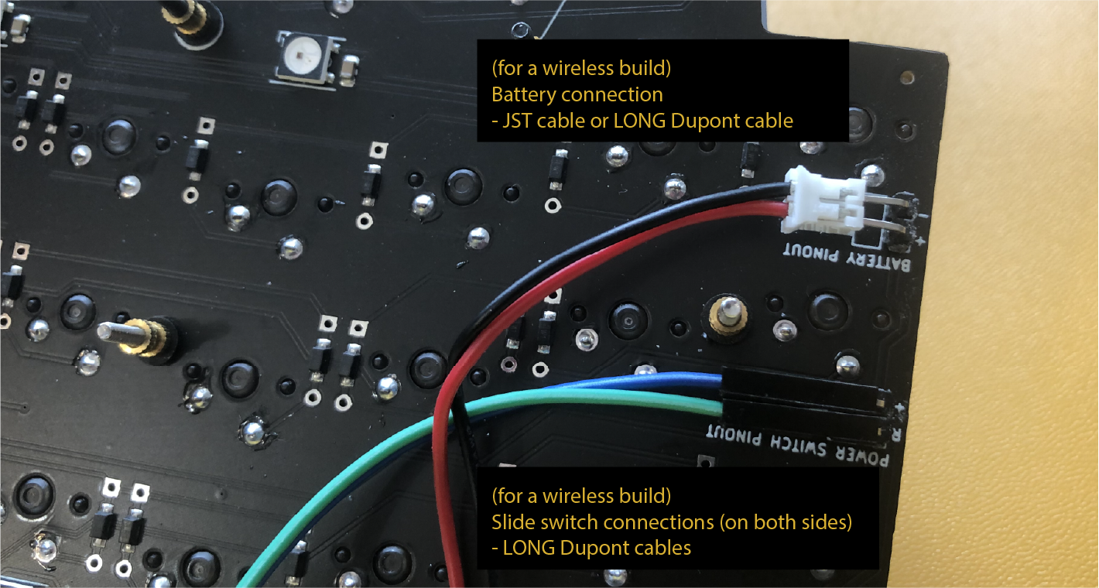
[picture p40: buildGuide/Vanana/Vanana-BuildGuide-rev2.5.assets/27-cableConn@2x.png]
27-cable conn@2x
   - To secure the battery onto the case, you may want to use a thin double-sided tape. Also, if you are using 0305 hot-swap sockets, the tip of the sockets may touch your battery when you close the case. Consider applying a thin non-conductive electrical tape to prevent the sockets to poke into the battery.

### Step 6. Closing the case.

**Parts you need:**

- 12 x m2 nuts
- 12 x m2 washers

**Steps:**

1. We are almost there. Arrange the PCB assembly and the case as shown in the photo below. If you are building a wired Vanana, you do not need any cables connected. Just toggle on the onboard RGB switch. 
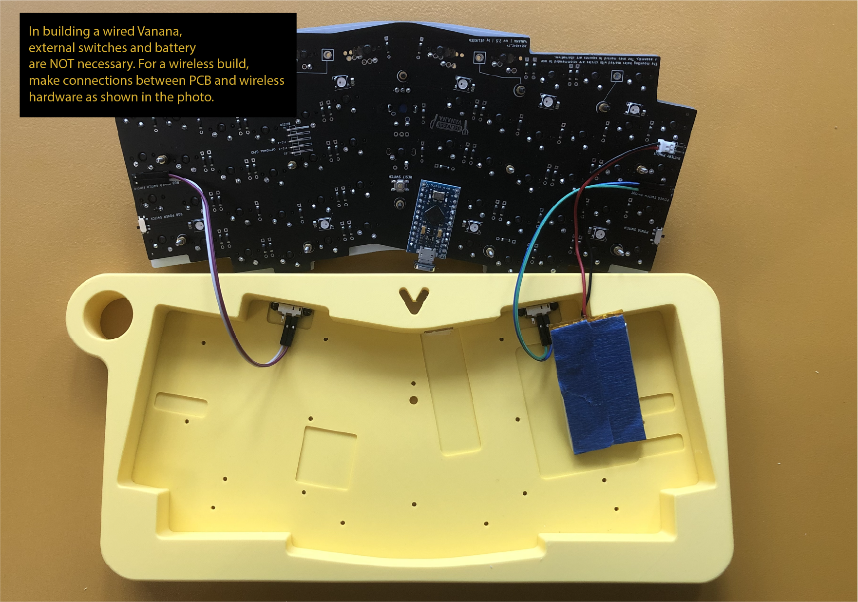
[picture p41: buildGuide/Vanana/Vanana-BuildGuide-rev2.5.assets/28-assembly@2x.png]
28-assembly@2x
   

2. Close the PCB assembly on the case.
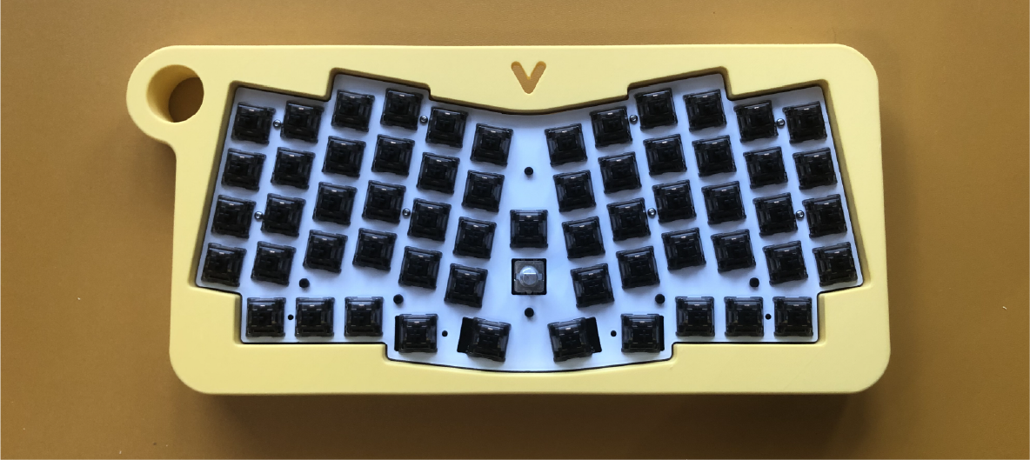
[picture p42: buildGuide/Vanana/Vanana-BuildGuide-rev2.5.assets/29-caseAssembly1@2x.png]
29-case assembly1@2x
    

3. Assemble the PCB assembly and the case using m2 nuts and washers.

   - Washers are optional. However, it will help reduce the possible damage to the case, which could be caused by over-tightening nuts or prolonged time of use. 

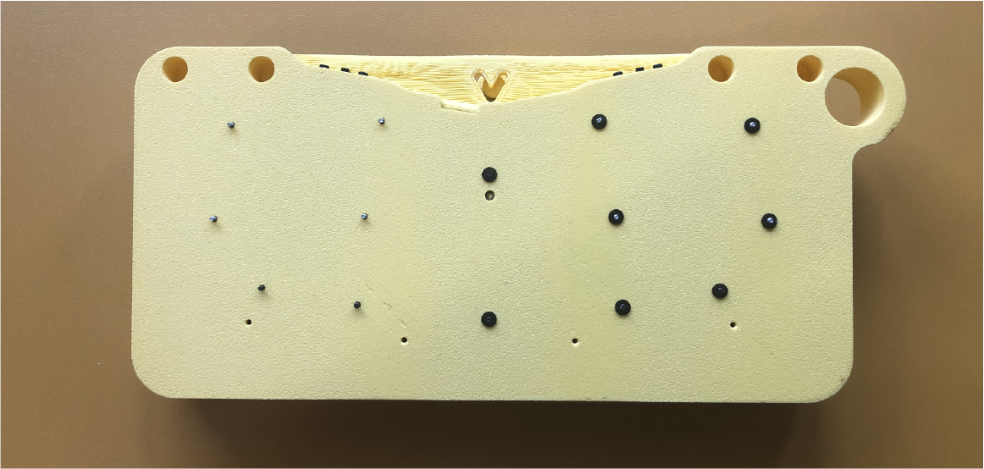
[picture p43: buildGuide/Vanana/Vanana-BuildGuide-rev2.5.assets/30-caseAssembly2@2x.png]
30-case assembly2@2x
   

4. Install the nuts included. Do not overtight the nuts. The nut we are using has a nylon insert, so it will lock in position without overtightening. 
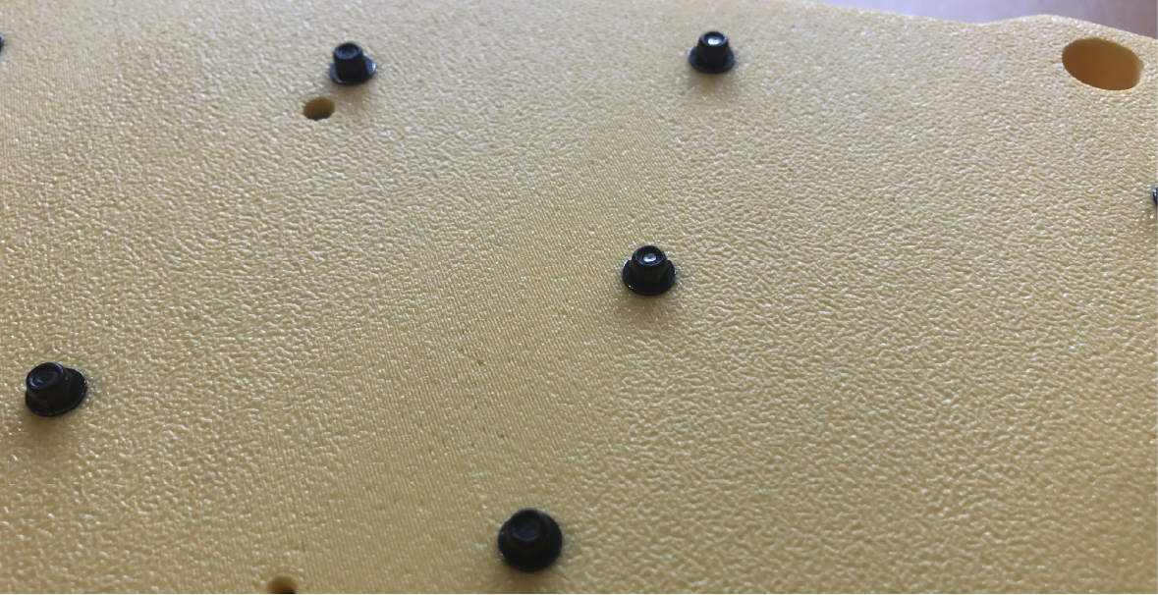
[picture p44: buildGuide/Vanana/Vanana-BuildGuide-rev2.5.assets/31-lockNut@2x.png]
31-lock nut@2x
    

5. Place rubber pad on the feet. 
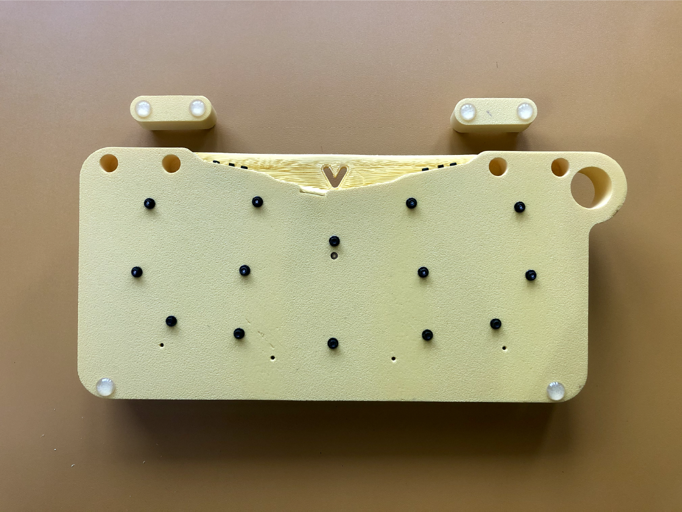
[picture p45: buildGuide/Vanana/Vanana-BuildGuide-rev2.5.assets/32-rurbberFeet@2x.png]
32-urbber feet@2x
   

### Step 7. Enjoy Vanana

You are all set! Install your favorite keycaps, and enjoy your delicious Vanana!

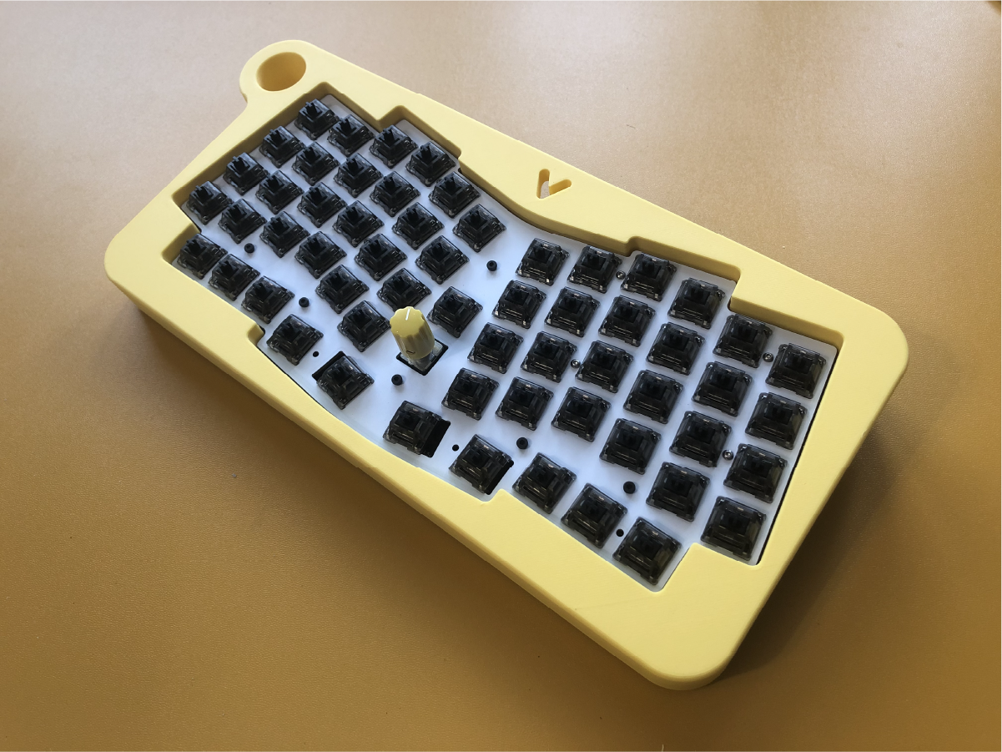
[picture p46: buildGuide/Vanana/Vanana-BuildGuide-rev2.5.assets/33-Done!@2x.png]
33-Done!@2x


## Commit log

2020-12-22 all uploaded
    [flatbread60_plate.dxf, hiProCase_rev2_wired.stl, hiProCase_rev2_wireless.stl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]
2021-01-17 waaffle middleware added
    [middleware_60config.stl]
2021-05-29 release vanana rev2.5 GB ACR case design
    [Vanana_rev2.5_GB_ACRcase_release.dxf]
2021-06-16 arc vanana label updated
    [Vanana_rev2.5_GB_ACRcase_release.dxf]
2021-08-14 updated Vanana build guide
    [flatbread60_plate.dxf, hiProCase_rev2_wired.stl, hiProCase_rev2_wireless.stl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]
2021-08-29 Remove ignored files
    [Vanana_rev2.5_GB_ACRcase_release.dxf, naanSplit_rev2.x-platecase_bottom.dxf, naanSplit_rev2.x-platecase_switch.dxf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]
2021-08-29 index fixed
    [vananaSplit_rev1.2-plateCase_switch.dxf]
